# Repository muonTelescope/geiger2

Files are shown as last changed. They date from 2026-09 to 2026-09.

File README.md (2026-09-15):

# geiger2

**In plain terms:** a pocket-sized gadget that listens for radiation with an old Russian Geiger tube, runs on two AA batteries, and talks to your phone over Bluetooth — so you can see counts without a custom app receiver. We’re designing a new board from scratch (not a clone of the 2014 wireless Geiger), with a proper high-voltage supply that can report its own voltage, then building it at JLCPCB.

Clean-sheet **Bluetooth Geiger counter**: nRF52832, CTC-5 (STS-5 / СТС-5) NOS Russian GM tube, regulated ~400 V bias with ADC readback, JLCPCB 2-layer PCB, authored in **tscircuit**.

Prior art: [wirelessGeigerCounter](https://github.com/sawaiz/wirelessGeigerCounter) (requirements only — not a port). See [docs/prior-art.md](docs/prior-art.md).

## Design study · September 2026

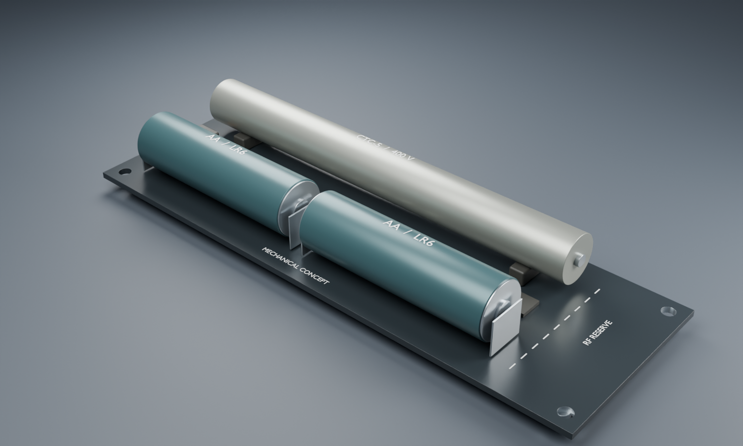
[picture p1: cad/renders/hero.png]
Mechanical concept


**Mechanical concept, not a routed PCB.** Proposed 140 × 48 mm envelope with
parallel CTC-5 and 2×AA, plus an RF reservation at one end. The tube, contacts and
HV components are stand-ins; [model provenance and views](cad/README.md).

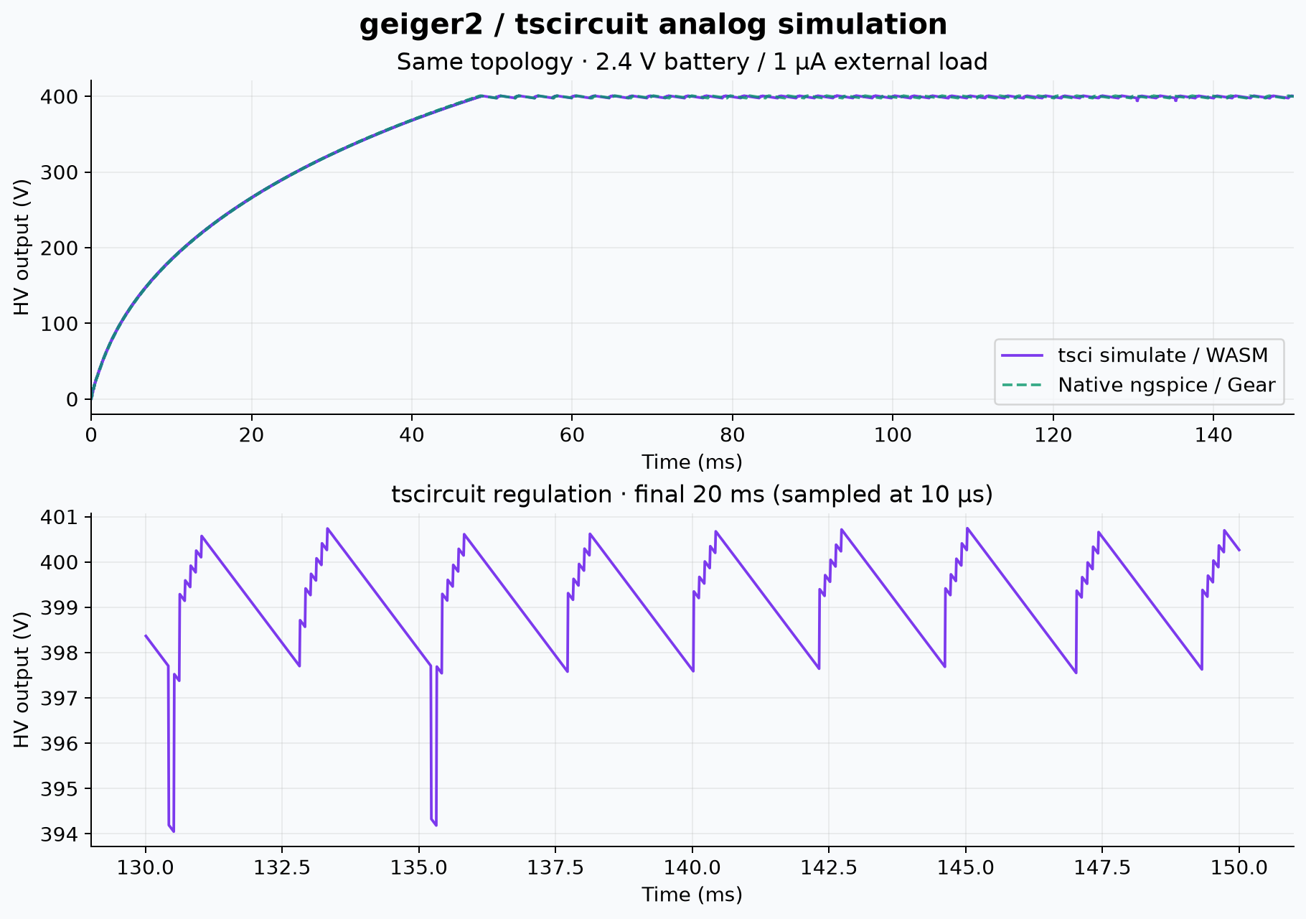
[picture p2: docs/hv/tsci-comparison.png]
tscircuit HV simulation


The exploratory HV model regulates near 400 V at a 1 µA external load across
1.8–3.2 V input. A permanently connected divider adds about 3 µA load. Real switch
drive, controller current and device losses still need validation.

- [HV calculations, plots, assumptions and reproduction](docs/hv/README.md)
- [Native/WASM comparison and discrepancy analysis](docs/hv/solver-comparison.md) — both simulation paths retained
- [Planned openEMS antenna analysis after PCB and enclosure design](docs/antenna-simulation.md)
- [JLC component selection and unresolved electrical checks](docs/component-selection.md)
- [HV ladder schematic](docs/hv/ladder-schematic.svg) · [verified tscircuit result](docs/hv/tsci-results.json)
- [Battery/load sweep](docs/hv/load-sweep.png) · [energy trade-offs](docs/hv/tradeoffs.png)
- [Top view](cad/renders/top.png) · [tube view](cad/renders/tube.png) · [profile](cad/renders/profile.png)
- [Download concept 3D model](cad/renders/geiger2-concept.glb)

## Goals

| Area | Decision |
|---|---|
| MCU / radio | **nRF52832-QFAA-R** (LCSC C77540) bare + **PCB inverted-F antenna** — [docs/mcu-rev-a.md](docs/mcu-rev-a.md) |
| Bluetooth | Advertising **plus** connectable **GATT** (config / telemetry) |
| Detector | CTC-5 / STS-5 halogen GM tube (NOS), ~110 mm × Ø12 mm |
| Layout | Handheld: **tube one long side**, **2×AA the other** (parallel, similar length); closed plastic shell |
| HV | Free-running regulated ~400 V + **ADC readback** (not MCU PWM) |
| Power | 2×AA, beacon clips MY-ZJ-3030 (`C964874`) / MY-AA-03 (`C19184098`); alkaline floor by default |
| Fab | JLCPCB **2-layer**; DRC from beacon **0.8.6 JLC-preferred** mins — [docs/jlcpcb-drc.md](docs/jlcpcb-drc.md) |
| UI (rev A) | Status LED; raw CPM in ads/GATT (µSv/h later) |
| PCB CAD | **tscircuit** board-as-code (muon3-style); 3D models in [cad/](cad/) |

## Tube (CTC-5 / STS-5)

| Parameter | Typical |
|---|---|
| Operating voltage | **360–440 V** (~390–400 V nominal) |
| Starting / counting | ~280–330 V |
| Plateau | ≥ 80 V, slope ≤ ~0.125 %/V |
| Anode load | 5–10 MΩ |
| Size | ~110 mm × Ø12 mm |
| Sensitive to | β / γ; SBM-20 class precursor |

Verify each NOS tube on the bench. HV setpoint mid-plateau with continuous readback.

## Architecture (draft)

```
2×AA → nRF52832 (direct VBAT)
         ├─ PCB inverted-F antenna (BLE adv + GATT)
         └─ free-running HV (~400 V)
                ├─ CTC-5 anode (5–10 MΩ)
                ├─ divider → SAADC HV_SENSE
                └─ pulse front-end → GPIOTE GM_PULSE
```

Open: final HV part numbers, CTC-5 clip MPN, RF match after layout, shell CAD.

## Repo layout

```
board/            tscircuit HV ladder review schematic (not a complete PCB)
cad/              3D models for renderings (AA, clips, nRF52832, CTC-5 approx)
docs/             HV studies, component review, MCU pin budget, prior art, JLCPCB DRC
sim/hv/           native and tscircuit SPICE sources
scripts/          reproducible simulations, plots and Blender renders
firmware/         nRF52 firmware (TBD)
hardware/pcb/     KiCad DRC seed only
manufacturing/    JLCPCB BOM/CPL when ready
```

## Manufacturing

- JLCPCB FR4, 2 layers, 1.6 mm, 1 oz, **black** mask, **white** silk, ENIG
- Rules: [docs/jlcpcb-drc.md](docs/jlcpcb-drc.md)

## Status

- MCU + pin budget locked; product locks (GATT, handheld shell, tube‖AA layout) documented
- 3D assets staged under `cad/models/` for board renders
- 16 native ngspice feasibility cases, plots and reproducible scripts generated
- tscircuit WASM simulation verified; HV ladder schematic matches SPICE connectivity
- Four Blender mechanical concept views and GLB generated
- Complete MCU/RF/HV schematic, real switch drive, routing and fabrication release remain open

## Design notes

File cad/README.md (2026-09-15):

# CAD / 3D models for geiger2 renderings

## Layout lock
Handheld: **CTC-5 along one long side**, **2×AA along the other** (parallel, similar ~110 mm length). Closed plastic shell later.

## Models in `models/`

| File | Source | Use |
|---|---|---|
| `aaCell.step` | x.drop-beacon `pcb/components/aaCell/` | AA cell body (×2) |
| `AA-LR6.FCStd` | same | FreeCAD parametric AA |
| `MY-AA-03.step` | beacon | Negative spring contact |
| `MY-ZJ-3030.step` | beacon | Positive contact |
| `NRF52832-QFAA-C77540.step` | tscircuit/EasyEDA modelcdn C77540 | SoC |
| `NRF52832-QFAA-C77540.obj` | same | SoC (mesh) |
| `QFN48.step` | beacon CC1310 QFN (fallback) | Only if C77540 model fails |
| `CTC5-approx.stl` | Generated Ø12×110 mm cylinder | Tube stand-in until better STEP |

## From wirelessGeigerCounter (`from-wirelessGeigerCounter/`)
Inventor history: `Acrylic Tube Housing.ipt`, `Back Cap.ipt` (SBM-20 era acrylic shell). **Not STEP** — needs Inventor/Fusion export for tscircuit. Useful as shell reference, not drop-in cadModel.

Better public STEP exists (GrabCAD / Marathon “SBM20-CTC5.step”, ~109.2×12 mm) — import manually if license OK; until then use `CTC5-approx.*`.

## tscircuit wiring
Prefer `cadModel={{ stepUrl, objUrl }}` like muon3 imports (EasyEDA CDN for JLC parts). For local files, use paths under `cad/models/` or host via modelcdn after `tsci` import.

## Generated mechanical concept

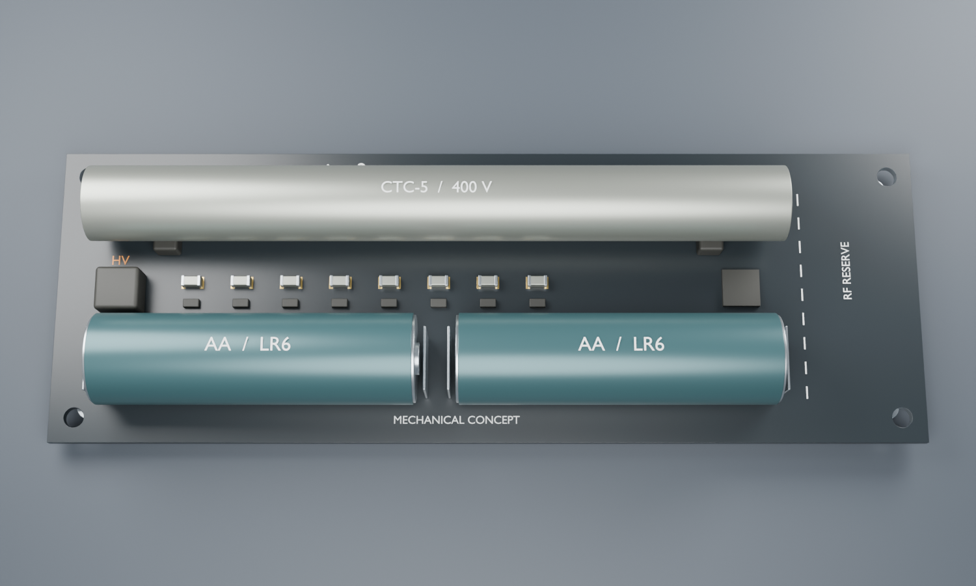
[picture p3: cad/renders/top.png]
Top view


Generated by `blender --background --python scripts/render_concept.py` from the
repository root. Four Cycles views: [hero](renders/hero.png), [top](renders/top.png),
[tube](renders/tube.png), [profile](renders/profile.png). The assembly is available
as [GLB](renders/geiger2-concept.glb); editable Blender scene regenerates in
ignored `build/geiger2-concept.blend`.

Proposed board envelope: **140 × 48 × 1.6 mm**. Tube center (-8, 13) mm, body
110 × Ø12 mm. AA centers (-36, -12) and (20, -12) mm, 50.5 × Ø14.5 mm envelope.
RF region begins at x=51 mm; this is a mechanical reservation, not a validated
antenna keepout or drawn RF element. Origin is board center.

The nRF52832 uses the supplied OBJ. Battery cells, battery contacts, tube, tube
supports and HV part envelopes are deterministic geometric stand-ins. Original
STEP files are retained in `models/`. FreeCAD's installed Python/Qt runtime failed
with an incompatible-processor error while tessellating STEP; `scripts/tessellate_models.py`
records the attempted conversion path. No converted meshes are claimed present.
The tube model is approximate, and final battery/tube contact fits remain open.

There is no routed KiCad PCB to export or DRC-check yet. These views establish
packaging intent; mounting holes, supports and component positions are provisional.
No copper traces, antenna geometry or enclosure qualification are inferred from
the image. The short-side room for RF and the central electronics corridor need
rechecking against the completed schematic and selected contact geometry.

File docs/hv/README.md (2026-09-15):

# HV converter feasibility study

**Status: simulated topology, not a validated hardware design.** The supply has
real SPICE inductors, capacitors, diodes and feedback, with a generic switch and
behavioral oscillator/comparator. These results establish an engineering baseline;
they do not establish efficiency, battery life or accuracy of a populated board.
No tube pulse amplitude or dead time is inferred from this load model.

## Topology and assumptions

2×AA → 1 mH inductor → switched node → four-stage half-wave Cockcroft–Walton
multiplier → approximately 400 V. Four stages mean **eight diodes and eight
capacitors**. The switched node's approximately 100 V peak-to-peak waveform pumps
the ladder; a DC 100 V rail alone would not do this.

Source: [converter.cir](../../sim/hv/converter.cir). The tscircuit simulation wrapper
is [hv.circuit.tsx](../../sim/hv/hv.circuit.tsx), with the subcircuit generated from
the same native source by [sync_spice_model.py](../../scripts/sync_spice_model.py).

| Parameter | Baseline |
|---|---:|
| Battery | 1.8 / 2.4 / 3.2 V, 0.5 Ω source resistance |
| Input capacitor | 22 µF ideal |
| Inductor | 1 mH, 8 Ω series DCR, linear (no saturation/core loss) |
| Clock | 10 kHz, 20 µs on-time, 50 ns edges |
| Power switch | ideal controlled switch, 2 Ω on, 30 pF drain capacitance |
| Diodes | generic model: 2 nA Is, n=1.7, 2 Ω Rs, 2 pF Cjo, 50 ns Tt, 250 V BV |
| CW capacitors | 8×10 nF effective; no ESR/leakage model |
| Monitor divider | 4×33 MΩ + 412 kΩ, always connected |
| Sense capacitor | 100 pF |
| Comparator | 1.242 V center, ±4 mV input hysteresis, 40 µs output RC |
| External load | 0 / 1 / 5 / 20 µA, smoothly reduced below 100 V for startup |
| Initial state | capacitors discharged; controller initially enabled |

The reference topology is motivated by [ADI CN0536](https://www.analog.com/media/en/reference-design-documentation/reference-designs/cn0536.pdf).
That design uses different drive conditions, values and feedback pickup. Its measured
current must not be reused as a geiger2 prediction. The proposed comparator family
is [TI TLV3012B](https://www.ti.com/lit/ds/symlink/tlv3012.pdf); its actual delay,
offset, hysteresis range, startup and reference tolerances need corner modeling.

## Calculations

For discontinuous inductor current, a first screen is:

- `Ipk ≈ VBAT × ton / L` → 36 / 48 / 64 mA at 1.8 / 2.4 / 3.2 V, before DCR.
- `Ecycle ≈ L × Ipk² / 2` → 0.648 / 1.152 / 2.048 µJ.
- At continuous 10 kHz those energies correspond to 6.48 / 11.52 / 20.48 mW,
  before converter losses. Burst regulation reduces the average.
- Divider ratio `(132 MΩ + 412 kΩ) / 412 kΩ = 321.38835`.
- Reference center `1.242 × 321.38835 = 399.164 V`; ideal comparator thresholds
  are approximately 397.879 and 400.450 V. Stored energy and delay cause overshoot.
- Divider current at 400 V is **3.021 µA**, and continuous dissipation **1.208 mW**.
  This exceeds a 1 µA external load's 0.4 mW. No-load is not zero HV load.
- SAADC input would be 1.2446 V at 400 V; input impedance and power sequencing
  still need design validation.

For equal-capacitance, continuously driven half-wave CW screening, with `n=4`:

`ΔV ≈ I / (f C) × (2n³/3 + n²/2 − n/6)`

`Vripple ≈ I / (f C) × n(n+1)/2`

At 4.02 µA total load, 10 kHz and 10 nF, these estimate 2.01 V sag and
0.402 V ripple. **Burst-mode ripple must come from the transient simulation**;
these equations assume continuous drive and do not predict comparator hysteresis.

## tscircuit analog simulation

tscircuit analog simulation and native comparison

Actual `tsci simulate analog` result: **849,452 adaptive points over 150 ms**, at
2.4 V input / 1 µA external load. It crosses 396 V at **47.020 ms**. In the
100–150 ms measurement window the mean is **399.267 V**, the range is
**394.051–402.112 V**, and modeled input current is **0.866 mA**. Maximum switch
voltage is **103.091 V**. [Machine-readable metrics](tsci-results.json) and
[sampled trace](tsci-trace.npz) are versioned.

The native and WASM startup curves agree closely. Native first-crossing metrics
use adaptive samples (46.820 ms); its 10 µs plot trace first crosses at 47.230 ms
because it misses an earlier narrow peak. WASM has deeper transient dips than the
Gear-integrated native result. **Numerical ripple/peak convergence is not yet
established**; do not use one solver's cleaner waveform as proof of hardware ripple.

The CLI emits ignored internal-node `.ic` and voltage-source probe warnings when
padding a custom `.subckt`. Per-element initial conditions remain in the model;
the requested HV/switch/sense outputs and battery current are present. Preserve
[the actual CLI run log](tsci-run.log); do not silently filter its warnings.

The simulation uses a five-port schematic macro for the full exploratory supply.
That macro's SOIC footprint is only a simulation placeholder, not a physical
HV module or an assembly part. The separate detailed ladder drawing below is
checked against the same source netlist.

Both simulation paths are retained. See the [aligned-window comparison](solver-comparison.md)
for ripple/current differences and the remaining convergence work.

## HV ladder review schematic

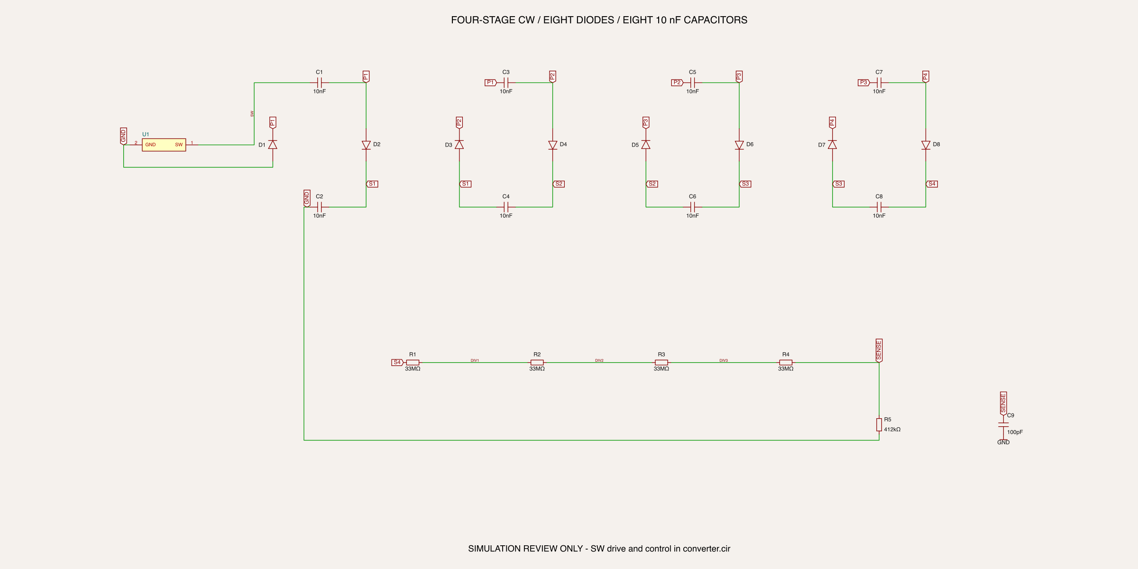
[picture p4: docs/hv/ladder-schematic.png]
tscircuit HV ladder schematic


[Vector schematic](ladder-schematic.svg) · [tscircuit source](../../board/hv-ladder.circuit.tsx).
U1 represents the switched-node drive; it is not an actual IC selection. S4 is
HV output. `scripts/check_hv_schematic.py` checks the built circuit's connectivity,
including diode polarity, and all divider/capacitor values against `converter.cir`.
It passes for 23 components and 14 nets. This is a subsystem review drawing, not
a completed MCU/pulse-front-end schematic or ERC/DRC fabrication release.

## Native ngspice sweep

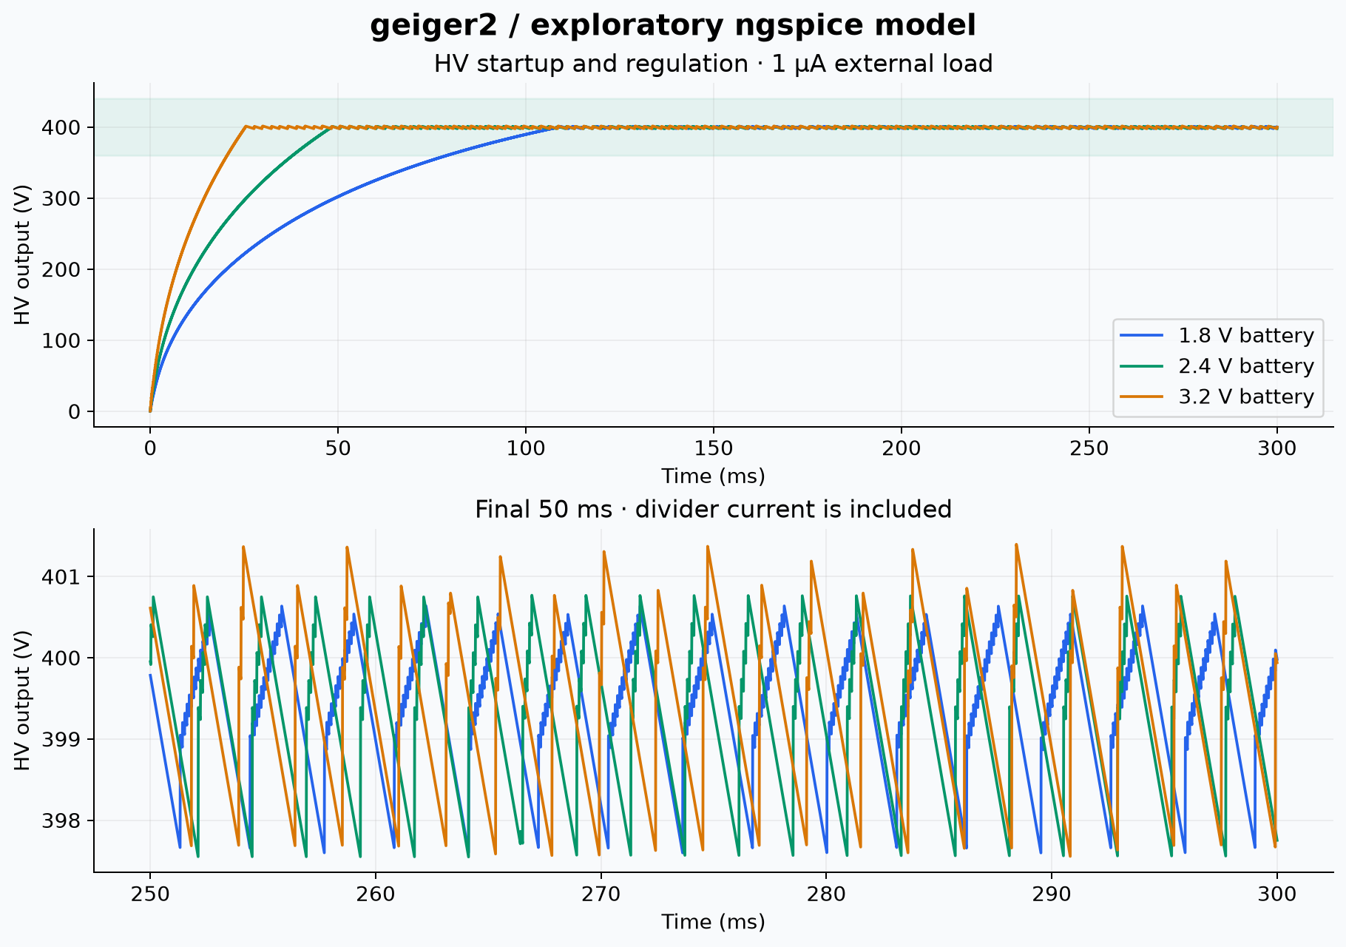
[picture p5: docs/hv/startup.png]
Startup and regulation


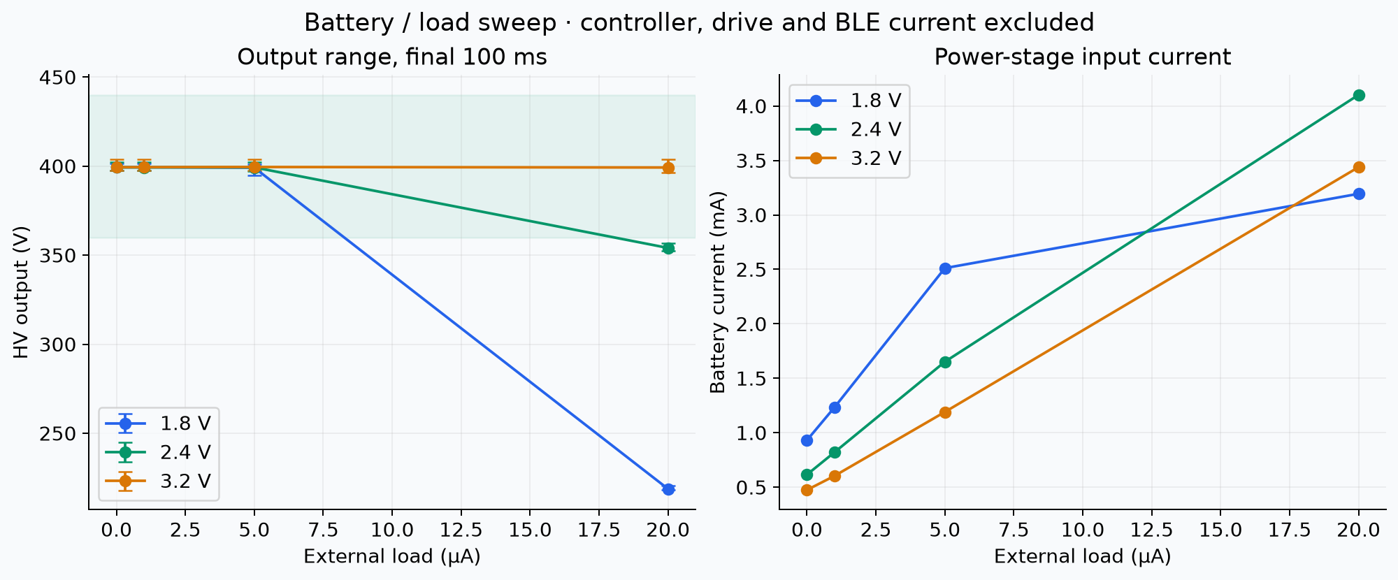
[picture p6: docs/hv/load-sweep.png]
Battery and load sweep


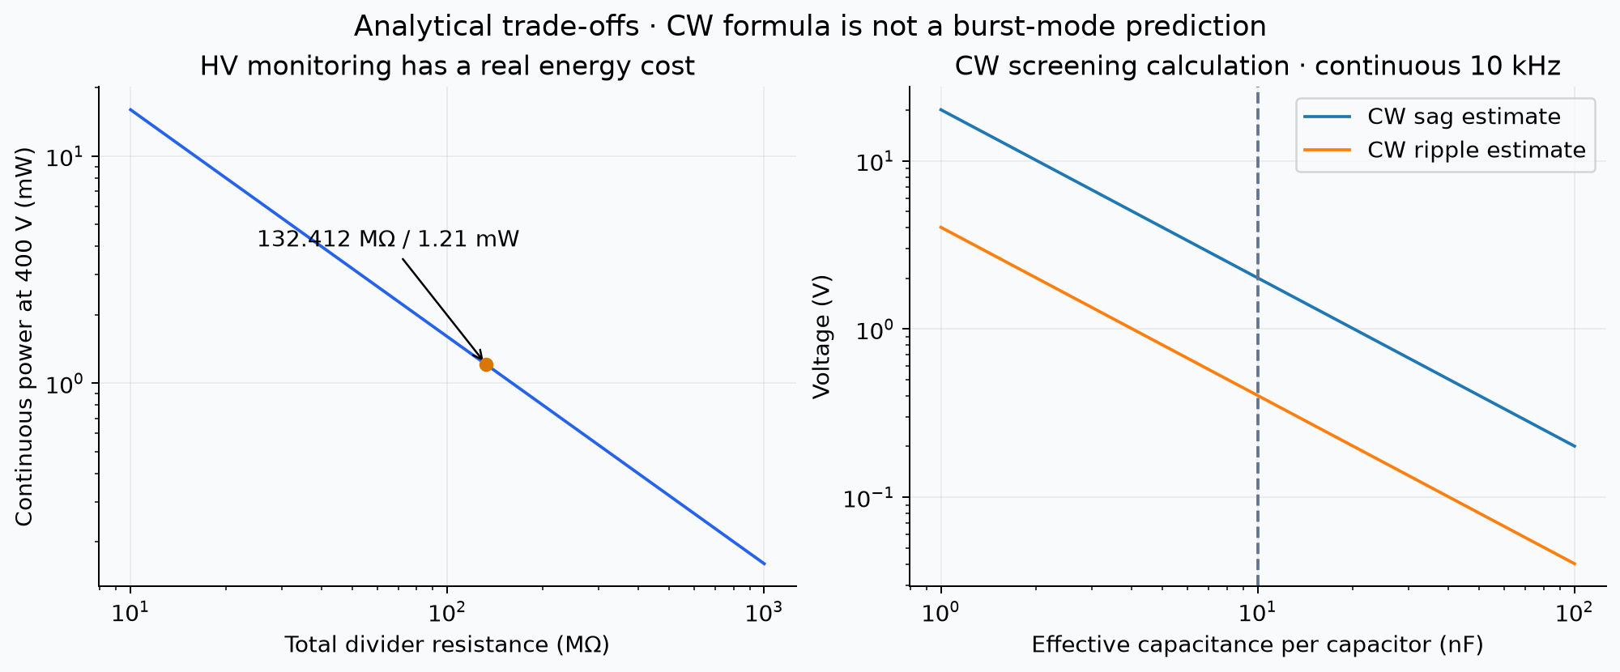
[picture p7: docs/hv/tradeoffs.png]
Analytical trade-offs


Full results: [CSV](results.csv) · [JSON](results.json). Native ngspice 47;
16 runs of 300 ms. Statistics use the final 200–300 ms window. That window is
**not necessarily settled** for slow-starting corners. Startup is first crossing
of 396 V, not a guarantee of subsequently staying in regulation.

At 1 µA external load:

| Battery | First 396 V crossing | Final-window HV range | Power-stage battery current |
|---|---:|---:|---:|
| 1.8 V | 104.7 ms | 397.60–401.30 V | 1.234 mA |
| 2.4 V | 46.8 ms | 397.55–402.09 V | 0.821 mA |
| 3.2 V | 24.4 ms | 397.55–403.85 V | 0.604 mA |

The 20 µA stress load is outside the low-battery capability in this model. It is
not a claimed tube count rate: actual charge per event is unknown. The 16 Ω DCR
and +20% L corners at 1.8 V / 5 µA do not reach 396 V within 300 ms; extend them
before making steady-state conclusions. The largest recorded switch voltage
across these cases is about 107 V; no avalanche, fault or parasitic signoff follows.

Current/efficiency columns include the modeled HV power path and divider. They
exclude oscillator/comparator supply current, real transistor drive energy, BLE,
LED, and real semiconductor/core/capacitor leakage and losses. A generic model's
reported efficiency is not a measured or worst-case converter efficiency.

## Reproduce

```sh
bun install --frozen-lockfile
bun run sim:sync
bun run sim:hv                   # actual tscircuit CLI / WASM, table saved as gzip
python3 scripts/analyze_tsci.py  # validate CLI data and regenerate comparison plot
bun run build:schematic
python3 scripts/check_hv_schematic.py
rsvg-convert -w 2400 dist/board/hv-ladder/schematic.svg -o docs/hv/ladder-schematic.png
python3 scripts/simulate_hv.py   # retained native ngspice sweep + plots
bun run sim:compare             # both runs, identical 100–150 ms metrics
```

`sim:hv` invokes the installed tscircuit CLI with a small Bun preload that saves
its full result table losslessly to `build/tsci/hv-table.txt.gz`. It changes output
serialization only; the solver and generated circuit are unchanged. Use
`bun run sim:hv:plain` for the unmodified terminal table. At this run size the
plain table is hundreds of MB. The pinned lockfile also includes explicit CLI
dependencies needed to resolve upstream packaging/export mismatches.

Python requires NumPy and Matplotlib; native sweep requires ngspice. Intermediate
adaptive data, run decks and logs are in ignored `build/hv/`; figures and summary
metrics are versioned. The native plot traces are linearized to 10 µs; stress and
power metrics use the original adaptive samples, so narrow peaks can exceed the
visible sampled plot envelope. The runner fails on incomplete/nonfinite data and
ngspice errors. Native integration uses Gear; the CLI's default integration can
differ, so compare startup/range rather than point-for-point switching phase.

## Work required before routing / fabrication

1. Select and simulate the actual low-voltage oscillator, HV switch and drive circuit.
2. Use the chosen inductor's DCR, tolerance, saturation and losses; extend slow corners.
3. Verify each diode's reverse stress, forward pulses and temperature-dependent leakage.
4. Add reference/divider tolerances, ADC buffer and power-sequencing behavior.
5. Simulate load steps, output short/open feedback, enable/disable and residual discharge.
6. Characterize the actual tube; model pulse charge separately from steady load sweeps.
7. Finish schematic, RF reference layout and HV-specific clearances; run ERC/DRC.

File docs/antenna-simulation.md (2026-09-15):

# Antenna validation with openEMS

**Planned; no antenna simulation has been run.** Start openEMS work after the
PCB layout is finalized and the enclosure is designed. The current mechanical
concept is insufficient for antenna tuning. Keep both existing HV simulation
workflows; openEMS adds electromagnetic analysis of the PCB inverted-F antenna.

## Freeze the geometry and inputs

Record revision hashes for PCB copper, board outline, stackup, antenna/feed and
matching-network reference plane, and closed-case CAD. Include batteries, battery
contacts, tube metal and other nearby conductors with their actual positions.
Specify substrate, solder-mask and shell permittivity/loss assumptions with
sources, and distinguish measured properties from estimates. Document simplified
geometry and omitted features. Preserve RF keepouts in the final assembly.

## Cases and outputs

| Case | Purpose |
|---|---|
| Bare PCB | Establish antenna/feed baseline |
| PCB with tube, batteries and contacts | Quantify nearby-metal loading |
| Complete assembly in closed shell | Evaluate enclosure detuning and radiation |
| Representative hand placement, with a documented material model | Assess sensitivity to handheld use |

Sweep across the BLE operating band with margin on both sides. Report input
impedance and S11 at the defined feed reference plane, resonant frequency,
radiation efficiency, realized gain and far-field patterns. Inspect surface
currents and local fields to locate unintended coupling. Separate mismatch loss
from radiation loss and state gain/power normalization conventions.

Use a feed-port model appropriate to the final antenna and matching network;
do not silently treat the radio's package pin as a calibrated 50 Ω plane.
Check mesh refinement, simulation decay, absorbing-boundary separation and
material/dimensional sensitivity before trusting a resonance or efficiency.
Use near-field-to-far-field transformation for radiation results. The official
[openEMS antenna tutorial](https://docs.openems.de/en/latest/python/openEMS/Tutorials/Simple_Patch_Antenna.html)
illustrates ports, S-parameters and far-field analysis; its patch geometry is not
the inverted-F geometry for this project.

## Deliverables and completion criteria

- Reproducible model scripts under `sim/antenna/`, with tool versions and frozen input revisions.
- Mesh/geometry renders, convergence tables, S11/impedance plots and radiation patterns under `docs/antenna/`.
- A report comparing the cases and recording approximations, unresolved sensitivities and proposed matching values.
- Raw field dumps in an ignored build directory; retain compact numerical results and plot sources in Git.

Create those directories with the actual simulation implementation. Confirm the
final matching network using VNA measurements of assembled hardware in its case;
follow with an over-the-air BLE check. Simulation informs tuning but does not
replace these measurements. Set quantitative acceptance targets before evaluating
the final antenna; none are claimed achieved by the current concept renders.

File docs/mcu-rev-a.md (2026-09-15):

# Rev A — MCU selection and pin budget

## Decision

| Item | Choice | Why |
|---|---|---|
| SoC | **Nordic nRF52832-QFAA-R** | BLE advertising + SAADC + GPIOTE is enough; no USB/Thread need |
| Package | QFN-48-EP 6×6 mm | Escape on **2-layer** (matches JLCPCB plan) |
| LCSC / JLC | **C77540** | Extended; SMT Economic + Standard assembly |
| Form | **Bare SoC** (not a module) | Same fab style as x.drop beacon; PCB antenna on-board |
| Antenna | **PCB inverted-F** (Nordic nRF52832 reference geometry) | User requirement; not DN024 (that’s TI sub-GHz) |
| HFCLK | 32 MHz crystal + load caps (NP0, Nordic values) | Required for radio |
| LFCLK | 32.768 kHz crystal on P0.00/P0.01 | AA life / RTC for CPM windows |
| DCDC | Enable internal DC/DC (inductor on DCC) | Lower radio current on 2×AA |
| Debug | SWDIO / SWDCLK + RESET; Tag-Connect TC2030 style like beacon | |

Rejected for rev A: nRF52840 (extra cost/memory unused), pre-certified modules (harder JLC BOM, fights “PCB antenna + JLC parts”), WLCSP (painful on 2-layer).

Certification note: bare SoC + PCB antenna means **we own** FCC/CE/Bluetooth qualification later. Acceptable for prototype rev A.

## Power (2×AA, beacon clips)

Copy beacon battery contacts (JLC assembly parts):

| Ref (beacon) | MPN | LCSC | Role |
|---|---|---|---|
| BT+ | **MY-ZJ-3030** | **C964874** | AA positive contact |
| BT− | **MY-AA-03** | **C19184098** | AA negative spring |

Two cells in series → VBAT ≈ 1.8–3.2 V into nRF52832 (1.7–3.6 V). No 3.3 V LDO required if the SoC runs direct from VBAT (beacon pattern). Reverse insertion via clip geometry only.

Mechanical cell outlines: copy `aaCell` from `~/enzo/x.drop-beacon/pcb/components/aaCell/`.

## Pin budget (QFN-48 GPIO map)

Fixed / non-GPIO (schematic only): `VDD`, `VSS`, `DEC1`–`DEC4`, `DCC`, `ANT`, `XC1`, `XC2`, `SWDCLK`, `SWDIO`.

| Net | Pin | Mode | Notes |
|---|---|---|---|
| XL1 | **P0.00** | LF crystal | 32.768 kHz |
| XL2 | **P0.01** | LF crystal | |
| **HV_SENSE** | **P0.02 / AIN0** | SAADC | Divided tube HV (~400 V → ≤1.8 V AIN). Filter near pin. |
| **VBAT_SENSE** | **P0.03 / AIN1** | SAADC | Optional VBAT divider for advertising battery state |
| NFC1 | P0.09 | **NC** | Leave unconnected; do not route under antenna |
| NFC2 | P0.10 | **NC** | |
| **GM_PULSE** | **P0.11** | GPIOTE IN | Active-low impulse from front-end (V6-style). Sense low, IRQ / PPI count. |
| **HV_EN** | **P0.12** | GPIO OUT | Enables free-running HV converter (not MCU PWM — so System OFF / deep sleep stays possible) |
| **LED_STATUS** | **P0.13** | GPIO OUT | Optional activity LED; series R for 2×AA |
| UART_TX | P0.14 | UART | Debug bring-up only; test pads OK |
| UART_RX | P0.15 | UART | |
| SPARE0 | P0.16 | GPIO | Test pad |
| SPARE1 | P0.17 | GPIO | Test pad |
| **RESET** | **P0.21** | RESET | External pull-up; SWD header |
| Remaining P0.04–P0.08, P0.18–P0.20, P0.22–P0.31 | — | **Unused / test pads** | Prefer leave as unconnected GPIOs with DNF test pads rather than tying |

### Layout constraints

- Keep **HV_EN** and HV magnetics away from `ANT` / match network and from `HV_SENSE` analog.
- Route `GM_PULSE` short; no long antenna-adjacent stubs.
- Follow Nordic nRF52832 QFN reference for RF match + PCB antenna clearance (metal-free keepout; no unrelated pads — beacon-style custom rule later).
- Prefer JLC **Basic** passives for decoupling; RF match = C0G/NP0 + high-Q L (per `kicad-bom` skill).

## Still open (next, not blocking this lock)

- Exact HV IC / boost topology (free-running, closed-loop, ADC readback) — separate doc
- CTC-5 tube spring/fuse clips (Ø12 mm) — JLC part pick
- Final RF match BOM after antenna geometry is drawn

## Skills path

User asked for `~/agent-skills`. That path did not exist; linked to `~/.codex/skills` (KiCad BOM / schematic / PCB / gerbers / footprint skills). Prefer LCSC field name **`LCSC`** on symbols for JLC BOM export (`kicad-bom` skill).

## Product locks (rev A)

- **BLE:** advertising **plus** connectable GATT (config/telemetry), not ads-only.
- **Mechanics:** closed plastic **handheld shell** — antenna keepout must account for hand and enclosure; shell CAD later.
- **Defaults:** status LED only; raw CPM in ads/GATT (µSv/h later); alkaline 2×AA floor; TC2030-style SWD.

## Antenna simulation milestone

Run [openEMS antenna analysis](antenna-simulation.md) after PCB layout and closed-case
design are finalized, including the tube, AA cells and contacts. Final RF matching
requires assembled-case measurement after simulation.

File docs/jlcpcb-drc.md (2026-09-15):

# JLCPCB 2-layer design rules (from x.drop beacon)

**Source:** Downloads fab pack
`/Users/sawaiz/Downloads/x.drop-beacon-0.8.6/pcb/beacon.kicad_pro`
(JLC-preferred mins). Do **not** copy git `master` `.kicad_pro` on
`~/enzo/x.drop-beacon` for a new board — that tree still has the older
0.1524 mm track / 0.127 mm hole / 0.5 mm silk set.

Custom rules seed: [`hardware/pcb/geiger2.kicad_dru`](../hardware/pcb/geiger2.kicad_dru).

GitHub reference: `teamsafehome/x.drop-beacon`.

## Order / cart (beacon convention)

| Option | Value |
|---|---|
| Layers | 2 |
| Thickness | 1.6 mm |
| Outer copper | 1 oz |
| Finish | ENIG |
| Solder mask | black (both sides) |
| Silkscreen | white |
| E-test | yes |
| Impedance control | none |
| PCBA | SMT **top only**, **Standard** |

KiCad stackup metadata alone does **not** configure the order — set these in the JLCPCB form.

### Stackup (from beacon.kicad_pcb)

F.Cu 0.035 mm (1 oz) / FR4 core 1.51 mm εr 4.5 / B.Cu 0.035 mm. Mask thickness 0.01. Copper finish ENIG.

## Board design rules (mm) — JLC preferred

| Parameter | Value |
|---|---|
| min_track_width / min_connection / min_clearance | **0.15** |
| zone min_clearance | **0.20** |
| min_copper_edge_clearance | **0.20** |
| min_hole_clearance / min_hole_to_hole | **0.20** |
| min_through_hole_diameter | 0.2 |
| min_via_diameter | **0.60** |
| min_via_annular_width | **0.15** |
| silk_line_width | **0.15** |
| silk text size / thickness | **1.0 / 0.15** |
| min_silk_clearance | **0.15** |
| min_text_height / min_text_thickness | **1.0 / 0.15** |
| fab text | 1.0 / 0.15 |
| solder_mask_min_width | **0.13** |
| pad_to_mask_clearance | 0 |
| tenting | front + back |
| blind/buried / microvias | off |
| drc_exclusions | empty (fix root causes; don’t waiver-farm) |

## Default netclass

- track **0.15**, clearance **0.15**, via **0.60 / 0.30**

## Vias

| Diameter | Drill | Use |
|---|---|---|
| **0.6** | **0.3** | Signal (default) |
| ≥ **0.45** pad | **0.2** | Thermal (avoid JLC Kelvin surcharge) |
| 1.0 | 0.6 | Power / mechanical |

**Do not** use 0.35/0.2 vias — JLC charges 4-wire Kelvin.

## Fab / export conventions we follow

- Gerbers.zip files at **archive root** (no nested folder)
- Separate PTH / NPTH Excellon, mm; shared drill/place origin
- Exclude non-SMT from BOM/PnP (headers, fiducials, tooling, cells)
- Tooling holes `1.152mm-ToolingHole`: **NPTH only, no paste**, keep mask openings (not tented)
- Silk: hide tiny 0402/LED refs; keep F.Fab 1.0/0.15; eyeball CPL for polarized parts

## Beacon-only rules (not copied)

Antenna keepout / DN024 radiator rules and J1 guide-hole 5 mil escape stay on the beacon. Re-add RF keepout once the nRF52 antenna geometry is chosen.

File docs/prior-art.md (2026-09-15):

# Prior art — wirelessGeigerCounter

Pulled from [sawaiz/wirelessGeigerCounter](https://github.com/sawaiz/wirelessGeigerCounter)
(branch [`firmware/v6-ble`](https://github.com/sawaiz/wirelessGeigerCounter/tree/firmware/v6-ble))
and related [Sawaiz/geigerControl](https://github.com/Sawaiz/geigerControl).
geiger2 is **not** a port of this hardware.

Built hardware used **SBM-20**, not CTC-5. CTC-5 ≈ STS-5 ≈ SBM-20 class
([gstube STS-5](https://www.gstube.com/data/4540/);
[PocketMagic](https://www.pocketmagic.net/tube-sts-5-%D1%81tc-5-geiger-tube/)).
No CTC-5 was measured on the bench in that project.

## Lineage

| Generation | MCU | Radio | Tube | HV | Notes |
|---|---|---|---|---|---|
| V6 (2014 boards) | ATtiny2313 SOIC | nRF24L01+ | SBM-20 | MCU Timer0 PWM boost (~400 V **open-loop**) | Source of truth: `firmware/v6-ble`, `pcb/v6/` (`fbc6006:PCB/TX/`) |
| V7 CAD | ATtiny2313 QFN | nRF24 | SBM-20 | ICM7555 | `pcb/schematic.dch` — **do not mix** with V6 FW |
| Wi-Fi-era concept | ESP8266/ESP-12F | Wi-Fi | SBM-20 (README) | Schmitt boost + CW + op-amp (Maxim AN3757) | Concept / renders; not the built V6 |
| geigerControl | ESP8266 | Wi-Fi | — | — | Captive portal / OTA / websockets — **no pulse counting** |

## CTC-5 / STS-5 (public datasheet class)

| Parameter | Value |
|---|---|
| Start / counting | 280–330 V |
| Advised working | **360–440 V** (V6 aimed ~400 V on SBM-20) |
| Plateau | ≥ 80 V, slope 0.125 %/V |
| Anode load | **5–10 MΩ** |
| Stray input capacitance | ≤ 10 pF; coupling 7–10 pF |
| Background (max, gstube) | ~27 cpm |
| Size | ~110 mm × Ø12 mm |
| Pulse amplitude | **unknown** — V6 never scoped the anode pulse; do not invent |
| Dead time | ~190 µs noted for SBM-20 in V6 FW notes; **not measured** for CTC-5 |

Halogen self-quench; the anode resistor is the circuit quench.

## V6 HV (what was actually built)

- Timer0 Fast PWM → PB2/OC0A → boost: L1 SDR1005-103KL 10 mH, Q1 STN2580, D1 RS1M, C1 10 nF / 1.5 kV
- Anode load **R1 = 4.7 MΩ** (BOM; slightly under 5–10 MΩ datasheet)
- OCR0A = 127 @ 1 MHz → ~3.91 kHz, ~49.6% duty (“Set to 400V”)
- **No 555 on V6.** No HV sense net. ATtiny2313 has **no ADC** (AIN pins used by nRF SPI)
- Cannot deep-sleep: PWM must keep running or HV collapses (`SLEEP_MODE_IDLE`)

## V6 pulse path

MMBT3904 inverter: 22k / 100k / 220 pF 630 V / 10k pull-up → **Impulse / PD2 active-low**, INT0 falling edge. Idle high.

## V6 power / radio

- Schematic symbol VL621; BOM: MPD BC12AAL **2×AA**, +3 V rail, no regulator
- nRF24L01+ bit-bang SPI: CE=PD6 (net **CN**), CSN=PD5, SCK=PB0, MOSI=PD4, MISO=PB1
- `firmware/v6-ble`: Grinberg BLE **advertisement spoof** (ADV_NONCONN_IND, name GM) — not real BLE/GATT
- OSH Park 2-layer historically; geiger2 targets JLCPCB instead

## Lessons for geiger2

1. **Closed-loop HV + ADC readback** is the real upgrade (V6 was open-loop, no telemetry).
2. **Free-running HV** (or dedicated controller) so the nRF52 can sleep — don’t clock HV from the MCU if you want power-down.
3. Prefer anode load in the **5–10 MΩ** datasheet window; keep anode stray capacitance low.
4. Use **real nRF52 BLE** — do not port the nRF24 whitening stack.
5. Don’t mix V6 firmware with V7 schematic; don’t expect geigerControl to count pulses.
6. Cite `pcb/v6/bom.xlsx` for historical parts; don’t invent pulse amplitudes.

## Useful links

- https://github.com/sawaiz/wirelessGeigerCounter/tree/firmware/v6-ble
- CAD: `pcb/v6/` · Firmware: `firmware/v6-ble/`
- Last ShockBurst TX: git `bf09a87` `code/avrTx` (removed from master in `050199b`)

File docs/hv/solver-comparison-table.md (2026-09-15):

| Metric | Native ngspice | tscircuit WASM | WASM − native |
|---|---:|---:|---:|
| startup_396_ms | 46.820355 | 47.020390 | +0.200035 |
| hv_mean_V | 399.303164 | 399.266855 | -0.036309 |
| hv_min_V | 397.574126 | 394.050600 | -3.523526 |
| hv_max_V | 402.117608 | 402.111900 | -0.005708 |
| hv_ripple_pp_V | 4.543482 | 8.061300 | +3.517818 |
| battery_mean_mA | 0.836584 | 0.865919 | +0.029335 |
| switch_peak_first_150ms_V | 103.106851 | 103.091300 | -0.015551 |

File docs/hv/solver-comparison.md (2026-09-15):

# Native and tscircuit HV simulation comparison

Both workflows are retained: native ngspice for battery/load/corner sweeps, and
`tsci simulate analog` for the board-as-code simulation path. They share the
exploratory power-stage topology generated from `sim/hv/converter.cir`.

## Results on identical windows

2.4 V battery, 1 µA external load, plus the permanently connected 132.412 MΩ
divider. Voltage and battery-current statistics use **100–150 ms in both runs**.
Startup is the first adaptive sample at or above 396 V; switch peak uses 0–150 ms.

| Metric | Native ngspice | tscircuit WASM | Difference |
|---|---:|---:|---:|
| First 396 V crossing | 46.820 ms | 47.020 ms | +0.200 ms |
| Mean HV | 399.303 V | 399.267 V | −0.036 V |
| Minimum HV | 397.574 V | 394.051 V | −3.524 V |
| Maximum HV | 402.118 V | 402.112 V | −0.006 V |
| Peak-to-peak HV | 4.543 V | 8.061 V | +3.518 V |
| Modeled battery current | 0.837 mA | 0.866 mA | +3.51% |
| Switch peak, first 150 ms | 103.107 V | 103.091 V | −0.016 V |

[Full precision table](solver-comparison-table.md) · [JSON](solver-comparison.json)

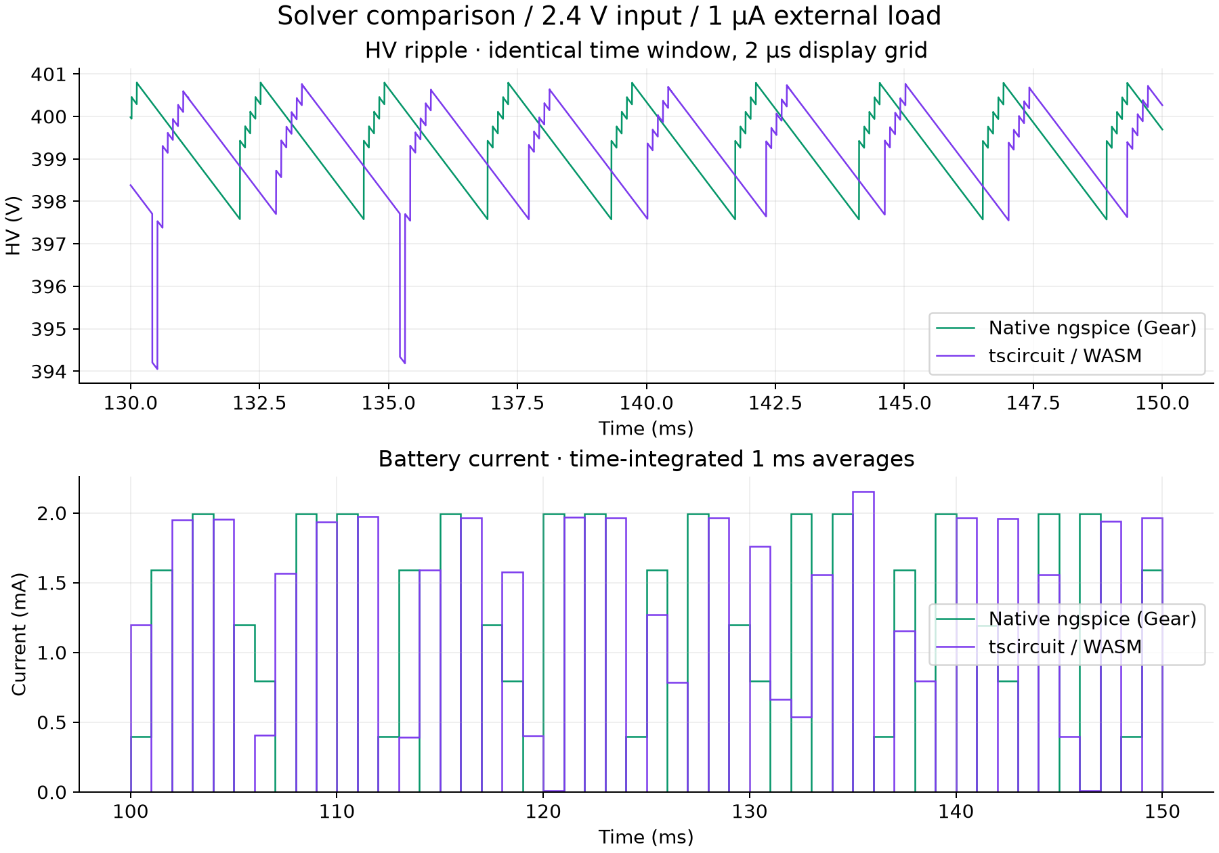
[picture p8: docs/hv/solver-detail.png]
Ripple and battery-current comparison


## Interpretation

Mean output differs by only 0.0091%, startup by 0.43%, and switch peak by
0.015%. These support consistent gross startup and regulation behavior for this
nominal case. They do not establish agreement at the other battery/load corners;
the existing 16-case sweep was run with native ngspice only.

WASM ripple is **77.4% larger**, driven primarily by deeper minimum-voltage dips.
Its modeled battery current is 3.51% higher over the same window. The plots show
burst timing differences; exact switching phase is not an appropriate pass/fail
criterion. The dip difference is unresolved and cannot yet be dismissed as a
numerical artifact or accepted as a physical prediction.

Both implementations use the ngspice family. This is a comparison across builds,
settings and circuit wrappers, not independent validation of the physical model.
Native ngspice 47 uses Gear integration, 2 µs maximum timestep, `reltol=0.001`,
`abstol=1p`, `vntol=1u`, and a 300 ms transient. The pinned tscircuit CLI uses
WASM through eecircuit-engine 1.7.4, a requested 2 µs step and 150 ms duration;
its integration/default tolerances are not asserted to match the native deck.
The CLI also reports ignored internal `.ic` and probe statements in the wrapper;
[the run log](tsci-run.log) preserves them. Per-element initial conditions remain.

The comparison integrates the original adaptive samples with exact interpolated
window boundaries. It does not average rows, which would overweight small steps.
The display uses a 2 µs grid and can miss narrow extrema; the table uses adaptive
data. The earlier native sweep uses 200–300 ms and reports 0.821 mA at this
operating point; that value must not be compared directly with the WASM 100–150 ms
current. Small differences from `tsci-results.json` arise from exact boundary
interpolation in this report. Use this report for cross-solver comparisons.

## Remaining validation

1. Export and archive the actual WASM deck; reconcile wrapper warnings and initial conditions.
2. Match solver settings and run length, then halve maximum timestep and tighten tolerances until extrema and energy converge. Record settings and changes in results.
3. Inspect the deep dips using internal ladder-node traces and switch/diode currents.
4. Repeat both paths at low/high battery and representative load corners.
5. Replace generic switch/diodes and behavioral control with selected device models and parasitics, then correlate with hardware.

These steps have not yet been completed. Neither current estimate includes
controller/drive supply consumption, BLE, or all real device losses. Use neither
as a battery-life prediction or component-stress signoff.

## Reproduce

With the dependencies in the [HV study](README.md) installed:

```sh
bun run sim:sync
bun run sim:native
bun run sim:hv
bun run sim:plots
bun run sim:compare
```

The comparison reads native `build/hv/v2.4_load1/metrics.txt` and the losslessly
compressed actual CLI table `build/tsci/hv-table.txt.gz`. Raw solver outputs stay
in ignored `build/`; scripts, summary metrics, PNG and SVG figures are versioned.

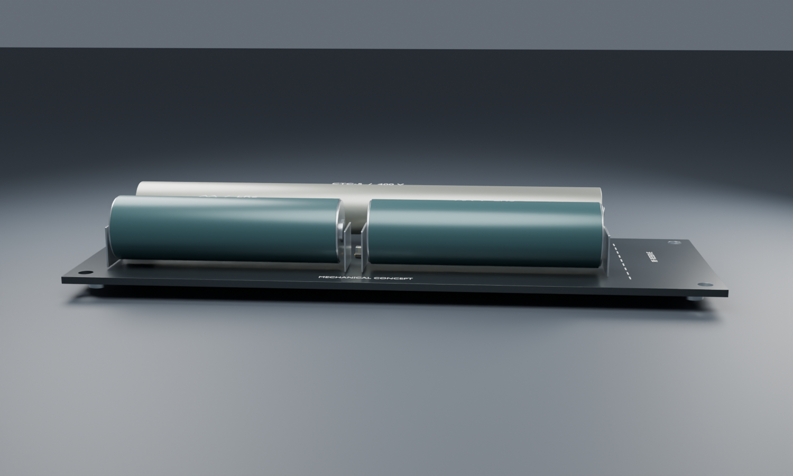
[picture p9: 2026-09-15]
cad/renders/profile.png

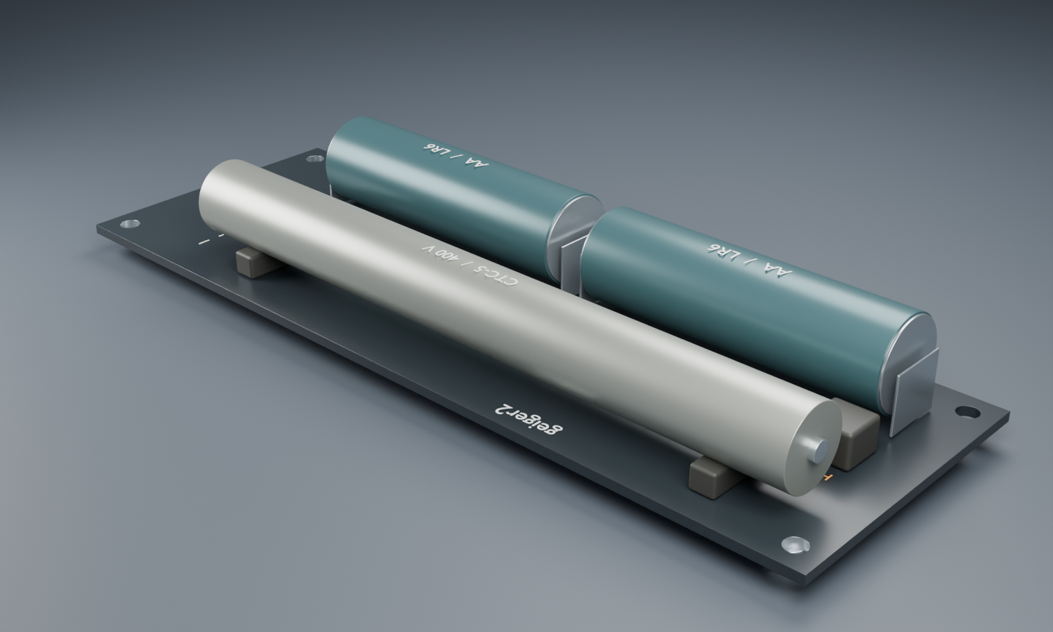
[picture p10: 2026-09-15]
cad/renders/tube.png

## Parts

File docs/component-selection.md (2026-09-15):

# Rev A component review

Package defaults accepted 2026-09-15: 0603 general passives, 0402 RF where the
Nordic reference requires them, larger HV packages to meet voltage/derating needs.
Top-side SMT, black mask, white silk, ENIG and the beacon 0.8.6 JLC fabrication
rules remain the manufacturing baseline. `~/agent-skills` resolves to
`~/.codex/skills`; this review follows kicad-bom, kicad-schematic and kicad-pcb.

## Selection ledger

These are design candidates, **not an assembly BOM**. Exact values and MPNs must
live in the eventual authoritative circuit source; manufacturing CSVs are generated
from that source. No placement/CPL or Gerbers are released from the concept model.
Database quantities are a 2026-09-15 snapshot, not reserved or live inventory.

| Function | MPN / LCSC | Package | Review / state |
|---|---|---|---|
| BLE MCU | Nordic NRF52832-QFAA-R / C77540 | QFN48 6×6 mm | Existing locked choice; database 25,901, Extended |
| HV comparator + reference | TI TLV3012BIDBVR / C20345924 | SOT-23-6 | Recommended; 1.65 V minimum supply, 1.242 V reference, typical 8 mV hysteresis; database 3,096, Extended |
| CW capacitors | TDK C3216C0G2J103JT000N / C342714 | 1206 | Recommended 10 nF, 630 V, C0G ±5%; database 2,413, Extended. Avoid unqualified X7R DC-bias loss |
| CW diodes | Diodes Inc. BAV21W-7-F / C155214 | SOD-123 | Candidate; catalog 200 V DC reverse rating, 50 ns recovery. Generic 250 V SPICE diode is **not** this vendor model; check actual reverse stress and hot leakage before locking |
| HV inductor | TDK B82442T1105K050 / C2041861 | 5.6×5 mm | Candidate 1 mH, 9.5 Ω DCR, catalog 150 mA rated / 310 mA saturation. Simulation baseline is 8 Ω, so not a drop-in validated choice |
| Oscillator | TI LMC555CMX/NOPB / C90760 | SOIC-8 | Candidate only: supply range includes depleted 2×AA. Output drive at 1.8 V, startup timing and oscillator power require validation |
| HV switch alternative | onsemi MMBTA42LT1G / C94389 | SOT-23 | Candidate BJT alternative to a boosted-gate MOSFET; base drive, storage time and SOA unresolved |
| Positive AA contact | MY-ZJ-3030 / C964874 | Imported beacon part | Existing choice, STEP retained; mating geometry not qualified by concept render |
| Negative AA contact | MY-AA-03 / C19184098 | Imported beacon part | Existing choice, STEP retained |
| Tube contacts | TBD | Ø12 mm tube compatible | No unverified fuse clip MPN assigned |
| HV divider | 4×33 MΩ + 412 kΩ | HV legs provisionally 1206 | Exact MPNs open. Search parser returned 33 **mΩ** for 33 **MΩ**: explicitly rejected those results |

Full returned metadata and datasheet links: [parts-snapshot.json](parts-snapshot.json).
Prefer Basic/Preferred when ratings and documentation meet the need. Lower catalog
price does not justify an undocumented HV part or substituting a different manufacturer's
similarly named device. IC alternatives above are not all installed in the model.

## Electrical design checks

- Each 33 MΩ divider leg sees about 99.7 V and 0.302 mW at 400 V. Working voltage,
  voltage coefficient, leakage and contamination dominate over resistor wattage.
  Target at least 200 V working rating per leg, verify temperature derating. Thin-film
  is preferred where available; do not invent a 33 MΩ thin-film MPN.
- A 412 kΩ lower divider leg gives 1.2446 V at 400 V. Its high source impedance
  requires a separately validated ADC buffer or sampling reservoir/acquisition time.
  Adding a large capacitor directly on the comparator node changes loop response.
- Eight 10 nF C0G capacitors avoid the large DC-bias uncertainty of Class II ceramics.
  Individual ladder capacitors see stage differences, not all 400 V, but pad-to-ground
  potentials still rise along the ladder. Capacitance tolerance and leakage remain real.
- The ideal switch's 2 Ω on-resistance is not evidence that a 100–200 V MOSFET is
  fully enhanced at 1.8 V. Gate threshold is not an on-resistance guarantee. Choose a
  validated gate supply/driver or explicitly model a BJT and its base-current cost.
- RF passives must be C0G/NP0 capacitors and high-Q inductors. No final RF match is
  chosen before reference geometry, board ground, enclosure and hand effects are assessed.
- The general 0.15 mm JLC clearance is **not an HV spacing rule**. Establish separate
  HV-to-LV and per-stage constraints from the intended environment and voltage stress;
  do not route the concept as a default-netclass board.

## Primary references

- [TI TLV3012 family datasheet](https://www.ti.com/lit/ds/symlink/tlv3012.pdf)
- [TI LMC555 datasheet](https://www.ti.com/lit/ds/symlink/lmc555.pdf)
- [Analog Devices CN0536](https://www.analog.com/media/en/reference-design-documentation/reference-designs/cn0536.pdf): topology reference, not a 1.8 V drop-in design.
- Component-specific datasheets returned by JLC lookup are linked in the snapshot.

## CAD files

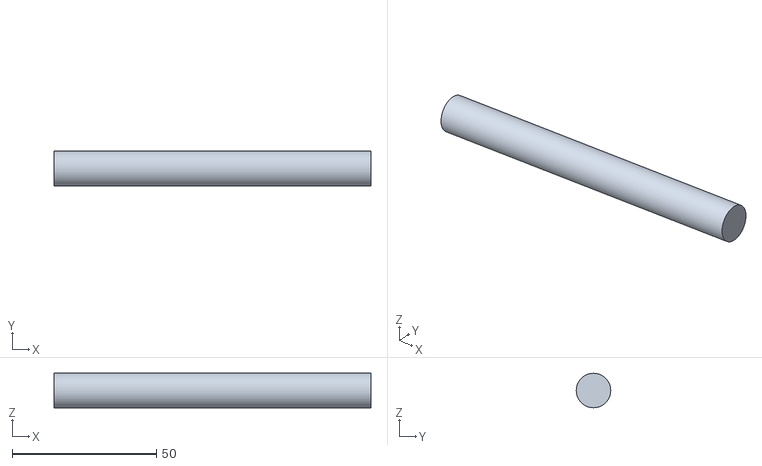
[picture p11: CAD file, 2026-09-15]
cad/models/CTC5-approx.stl
110.0 x 12.0 x 12.0

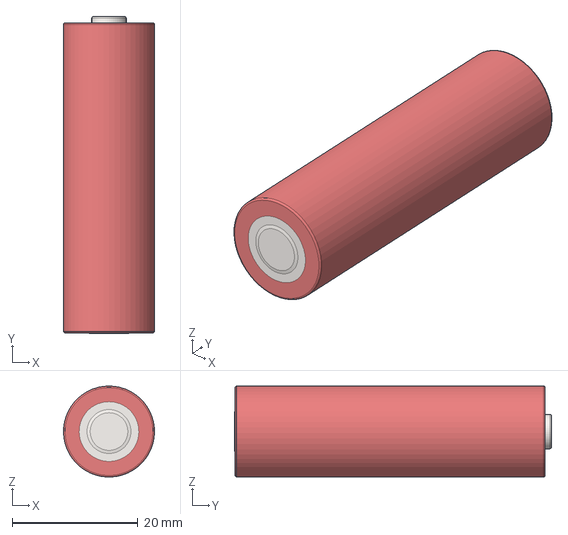
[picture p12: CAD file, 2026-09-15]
cad/models/aaCell.step
14.5 x 50.5 x 14.5 mm

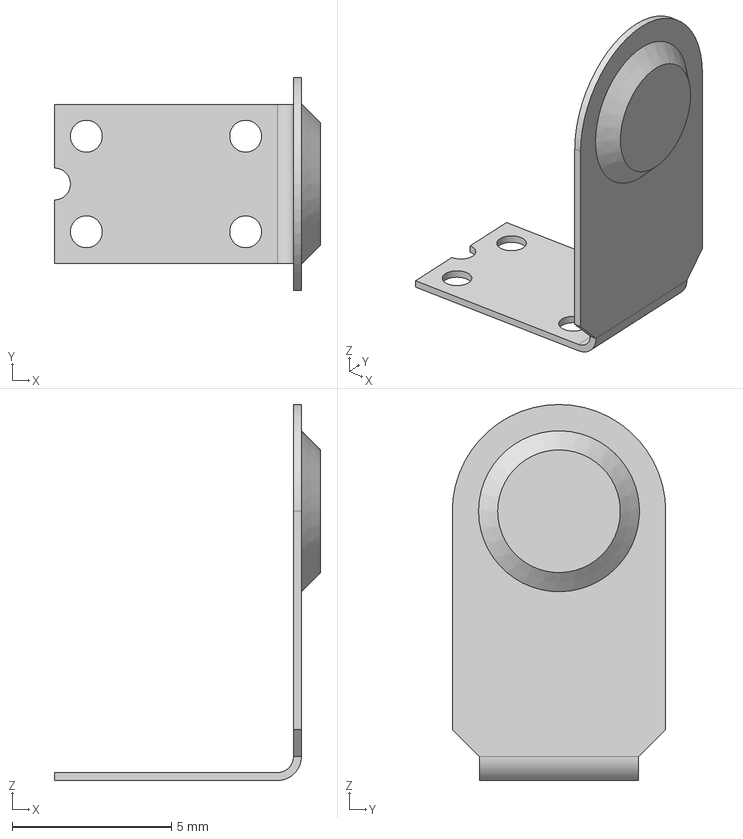
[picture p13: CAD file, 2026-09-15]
cad/models/MY-ZJ-3030.step
8.35 x 6.70 x 11.8 mm

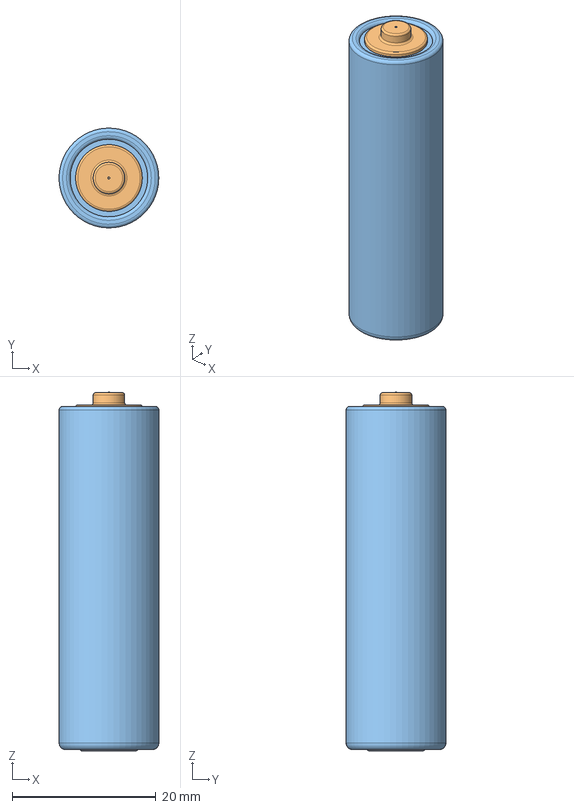
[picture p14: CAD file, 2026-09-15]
cad/models/AA-LR6.FCStd
13.9 x 13.9 x 50.0 mm

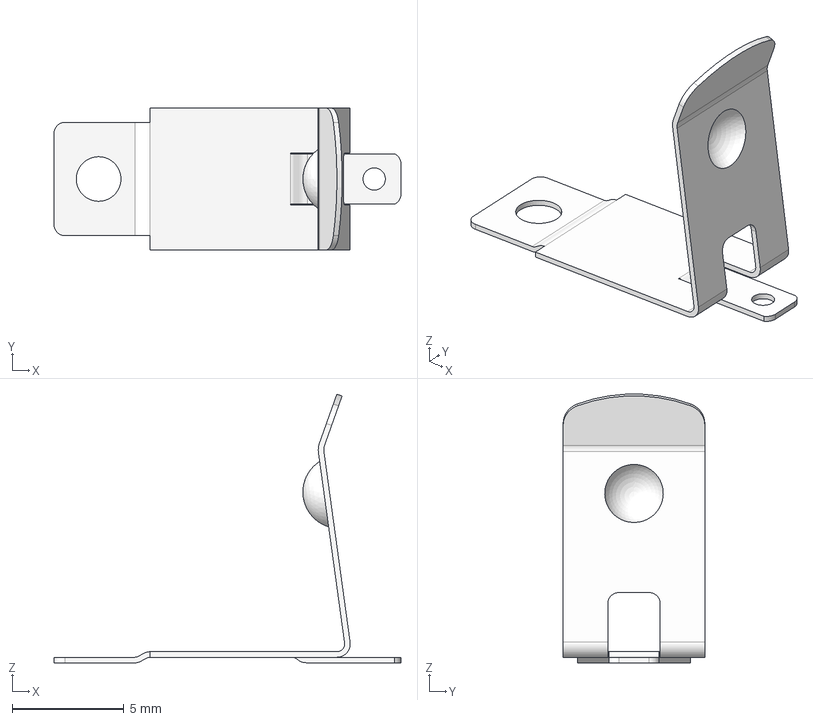
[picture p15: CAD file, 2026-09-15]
cad/models/MY-AA-03.step
15.5 x 6.35 x 12.0 mm

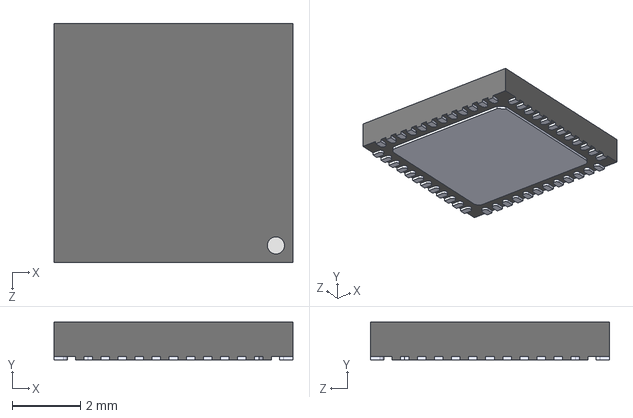
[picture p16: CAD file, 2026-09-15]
cad/models/QFN48.step
7.00 x 1.10 x 7.00 mm

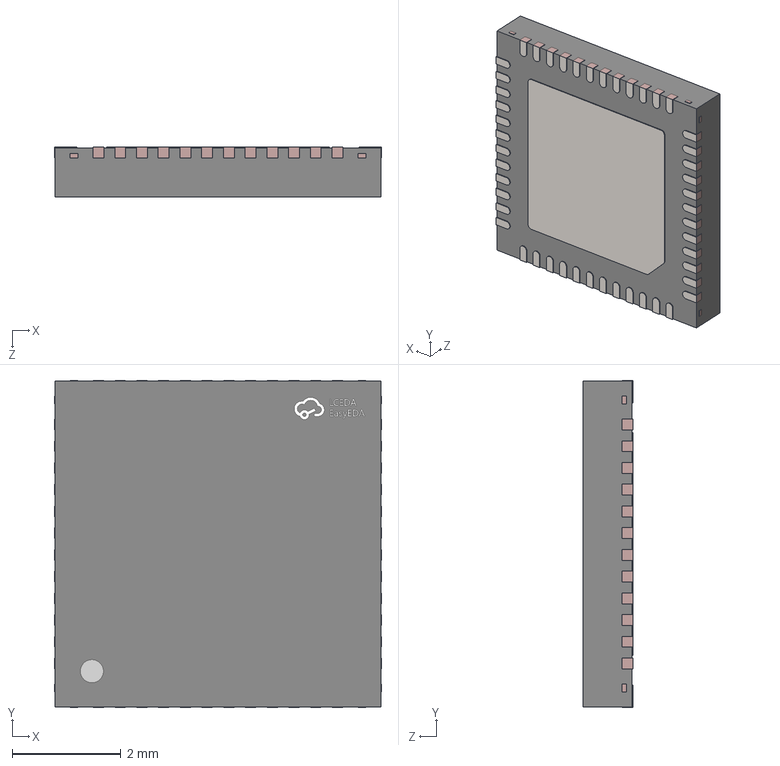
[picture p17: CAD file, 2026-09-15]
cad/models/NRF52832-QFAA-C77540.step
6.02 x 6.02 x 0.921 mm

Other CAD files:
cad/from-wirelessGeigerCounter/Acrylic Tube Housing.ipt
cad/from-wirelessGeigerCounter/Back Cap.ipt
cad/models/NRF52832-QFAA-C77540.obj

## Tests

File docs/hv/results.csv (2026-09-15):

case | vbat | load_uA | hv_mean | hv_min | hv_max | ripple_pp | startup_ms | peak_switch_v | peak_inductor_mA | input_mA | power_stage_efficiency | within_360_440
v1.8_load0 | 1.8 | 0.0 | 399.34345252601855 | 397.635084 | 401.312453 | 3.6773689999999988 | 95.6203516 | 101.697643 | 32.6765896 | 0.9314683799943755 | 0.7183347650409088 | True
v1.8_load1 | 1.8 | 1.0 | 399.3625697697716 | 397.597165 | 401.303809 | 3.706643999999983 | 104.72046 | 101.687979 | 32.6767609 | 1.2338580634672536 | 0.722156099959698 | True
v1.8_load5 | 1.8 | 5.0 | 399.1196122716452 | 394.821433 | 401.215416 | 6.3939829999999915 | 200.92041999999998 | 101.629625 | 32.6416317 | 2.5113248222401143 | 0.7076046772394806 | True
v1.8_load20 | 1.8 | 20.0 | 218.77548753709956 | 218.175543 | 220.604181 | 2.4286380000000065 |  | 57.8126747 | 32.6415342 | 3.193788366376469 | 0.8239915844596931 | False
v2.4_load0 | 2.4 | 0.0 | 399.29601508407126 | 397.63131 | 402.22234 | 4.591029999999989 | 45.1204561 | 103.093855 | 43.5292545 | 0.6154612459282691 | 0.8151784365808289 | True
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

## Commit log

2026-09-15 Bootstrap geiger2: README, prior art, JLCPCB DRC from x.drop beacon
    Clean-sheet nRF52 + CTC-5 design notes; extract wirelessGeigerCounter lessons;
    seed KiCad DRC for JLCPCB 2-layer fab.
2026-09-15 Align DRC with beacon 0.8.6 JLC-preferred mins; refine prior art
    Use Downloads pack rules (0.15 mm track/clearance, 0.6 mm vias, silk 1.0/0.15)
    instead of older git-master 6 mil set. Expand wirelessGeigerCounter notes from
    the agent handoff (SBM-20 built, CTC-5 datasheet class, V6 HV/pulse gotchas).
2026-09-15 Lock rev A MCU: nRF52832-QFAA-R + PCB antenna pin budget
    Select bare C77540 QFN-48 for JLC SMT, Nordic inverted-F antenna, 2xAA beacon
    clips (MY-ZJ-3030/MY-AA-03), and GPIO map for HV sense, pulse, and HV enable.
2026-09-15 Add layman README abstract, layout locks, and 3D model assets
    Document handheld tube‖AA layout, BLE GATT, and stage STEP/STL models
    (AA clips, nRF52832 C77540, CTC-5 approx) plus wirelessGeiger Inventor refs.
    [AA-LR6.FCStd, Acrylic Tube Housing.ipt, Back Cap.ipt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]
2026-09-15 Add reproducible HV studies, tscircuit sources and mechanical renders
    [results.csv]
2026-09-15 Verify tscircuit analog results and publish checked HV schematic
2026-09-15 Compare retained HV solvers and plan enclosure-aware antenna analysis
